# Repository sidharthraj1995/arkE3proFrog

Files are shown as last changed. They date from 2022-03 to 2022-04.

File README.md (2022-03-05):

# arkE3proFrog

- [arkE3proFrog](#arke3profrog)
- [1. Introduction](#1-introduction)
- [2. Hardware](#2-hardware)
  - [2.1. Motion](#21-motion)
    - [X axis](#x-axis)
    - [Y axis](#y-axis)
    - [Z axis](#z-axis)
    - [E](#e)
  - [2.2. Hotend](#22-hotend)
  - [2.3. Electronics](#23-electronics)
- [3. Firmware](#3-firmware)
- [4. Slicer Configuration](#4-slicer-configuration)

# 1. Introduction

Started with stock Creality Ender 3 Pro - Microcenter $99 deal, to learn about the 3D printing.

Replaced the motherboard to employ TMC2208 stepper drivers, linear rails for better motion, dual Z lead
screw for stable printing, Haldis 3D Frog extruder w/ Volcano hotend for HSHF printing, MOSFET for heatbed 
and hotend power, inductive probe for ABL and PEI spring sheet for great first-layer adhesion and large 
touch screen for easy interface.

Running Octoprint on AtomicPi using Docker.

# 2. Hardware

## 2.1. Motion

### X axis

    - Stock Creality 42-34 Stepper Motor.
    - TMC2208
    - MGN12C Linear Rail

### Y axis

    - Stock Creality 42-34 Stepper Motor.
    - TMC2208
    - MGN12C Linear Rail

### Z axis

    - Dual Z setup with 42-34 Stepper Motors.
    - TMC2208
    - V-Slot

### E

    - LDO-36STH20-1004AHG
    - TMC2208
    - Direct Drive setup

## 2.2. Hotend

    - Haldis 3D Frog Extruder w/ Volcano Hotend
    - 24V 50W heat cartridge
    - E3D Semitec 104NT

## 2.3. Electronics

    - BTT SKR 1.4T
    - BTT TFT70 V3.0
    - MOSFET for Hotbed and Hotend
    - ABL: Generic Inductive probe LJ18A3-8-Z/AX

# 3. Firmware

Coming soon.

# 4. Slicer Configuration

Coming soon.

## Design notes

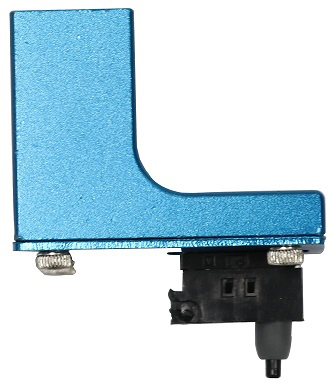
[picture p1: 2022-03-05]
config/Configurations-bugfix-2.0.x/config/examples/delta/Anycubic/Kossel/images/Version1Probe.jpg

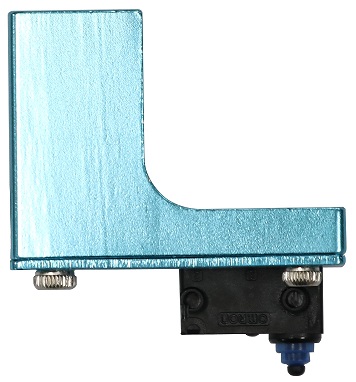
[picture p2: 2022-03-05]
config/Configurations-bugfix-2.0.x/config/examples/delta/Anycubic/Kossel/images/Version2Probe.jpg

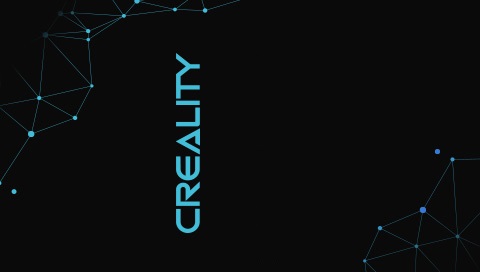
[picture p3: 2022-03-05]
config/Configurations-bugfix-2.0.x/config/examples/Creality/Ender-3 V2/DWIN_SET/0_start.jpg

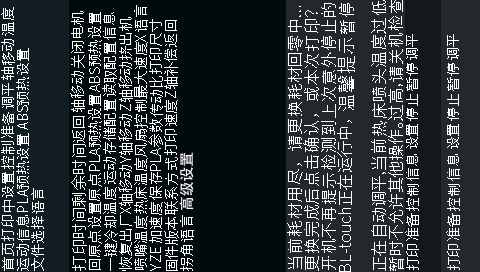
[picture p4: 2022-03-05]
config/Configurations-bugfix-2.0.x/config/examples/Creality/Ender-3 V2/DWIN_SET/2_Chinese.jpg

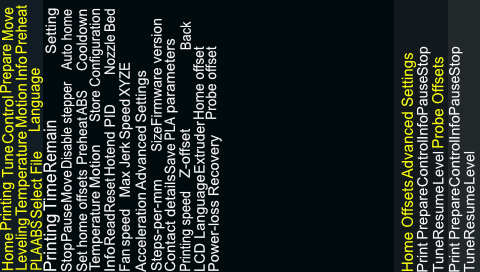
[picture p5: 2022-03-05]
config/Configurations-bugfix-2.0.x/config/examples/Creality/Ender-3 V2/DWIN_SET/1_English.jpg

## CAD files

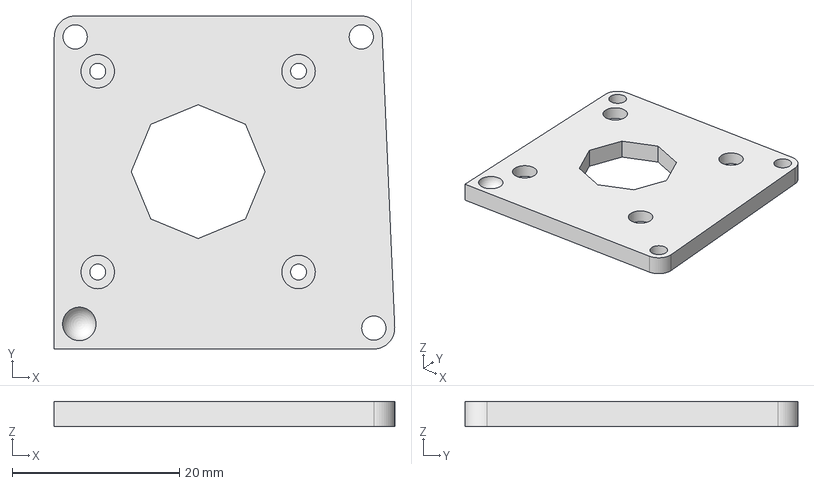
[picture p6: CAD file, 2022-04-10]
3020_4020_fanAdapter/30to40_adapter_v13.FCStd
40.7 x 39.8 x 3.00 mm

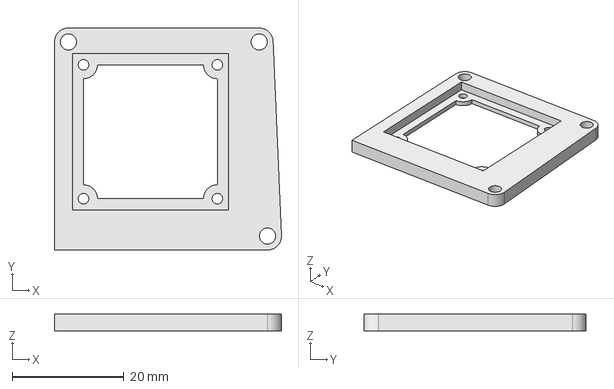
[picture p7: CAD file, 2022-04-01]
3020_4020_fanAdapter/30to40_adapter_v06_midLeft.FCStd
40.7 x 39.8 x 3.00 mm

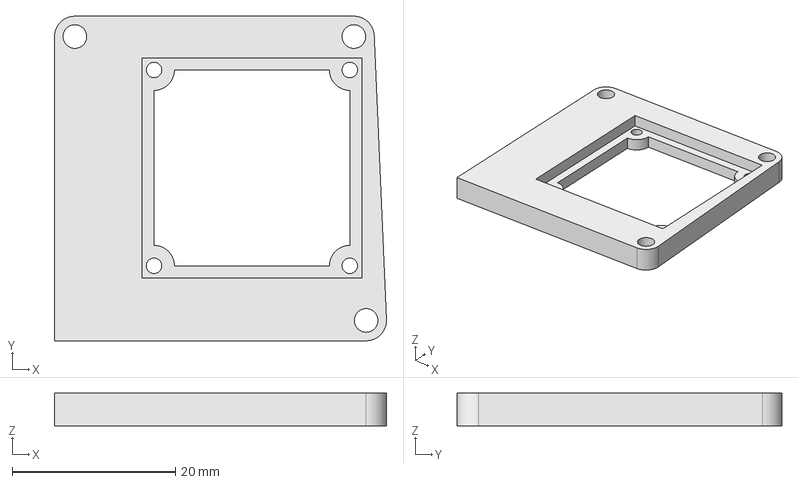
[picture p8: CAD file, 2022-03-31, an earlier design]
3020_4020_fanAdapter/30to40_adapter_v05.FCStd
40.7 x 39.8 x 4.00 mm

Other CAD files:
3020_4020_fanAdapter/30to40_adapter_v05.stl
3020_4020_fanAdapter/30to40_adapter_v13.stl

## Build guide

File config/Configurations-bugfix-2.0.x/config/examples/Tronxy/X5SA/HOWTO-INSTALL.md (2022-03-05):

# Table of Contents <!-- omit in toc -->
- [Save Printer Settings (Optional, but recommended)](#save-printer-settings-optional-but-recommended)
- [Configuring Marlin for your Printer](#configuring-marlin-for-your-printer)
  - [1. Board Version](#1-board-version)
  - [2. Bed size](#2-bed-size)
  - [3. Stepper Drivers](#3-stepper-drivers)
  - [4. Steps / mm](#4-steps--mm)
  - [5. Other Marlin Config](#5-other-marlin-config)
- [Backup your Chitu Firmware (Optional, but strongly recommended)](#backup-your-chitu-firmare-optional-but-strongly-recommended)
- [Flashing Marlin JUST USING SD](#flashing-marlin-just-using-sd)
- [Flashing Marlin Firmware MANUALLY (OBSOLETE!)](#flashing-marlin-firmware-manually-obsolete)
- [Known Issues](#known-issues)

# Save Printer Settings (Optional, but recommended)

You can (OR MUST) dump the current settings of your printer. It may help you to figure out some configs, like steps/mm of your extruder.

1. Create a file named `savesettings.gcode` with the following content:
```
M6046 ; sdcard access
M8512 "currentconfig.gcode" ; save settings to file
```
2. Save it on the printer's SD card
3. Put the card in the printer and "print" this file
4. The printer won't do anything. Just wait a few seconds and stop the print.
5. Your current printer settings are stored in the file: `currentconfig.gcode`

You can read more about it in [this guide](https://www.facebook.com/notes/tronxy-turnigy-x5s-x5sa-x3s-3d-printer-drucker-users/tronxy-firmware-configuration-guide-by-keith-varin-addermk264bit-tuning/649799805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).

Thanks to KEITH VARIN.

# Configuring Marlin for your Printer

You need to edit `Configuration.h` to set up your printer.

## 1. Board Version

For ***V5*** and ***V8***

```cpp
// For V5 and V8
#define MOTHERBOARD BOARD_CHITU3D_V5
```

For ***V6***

```cpp
// For V6
#define MOTHERBOARD BOARD_CHITU3D_V6
```

## 2. Bed size

```cpp
// The size of the printable area
#define X_BED_SIZE 330
#define Y_BED_SIZE 330
...
#define Z_MAX_POS 400
```

## 3. Stepper Drivers

Some Pro models have TMC drivers. The non-Pro models have generic A4988 drivers.

Non-Pro (without TMC Drivers):

```cpp
/**
 * Stepper Drivers
 * ...
 */
#define X_DRIVER_TYPE  A4988
#define Y_DRIVER_TYPE  A4988
#define Z_DRIVER_TYPE  A4988
//#define X2_DRIVER_TYPE A4988
//#define Y2_DRIVER_TYPE A4988
//#define Z2_DRIVER_TYPE A4988
//#define Z3_DRIVER_TYPE A4988
//#define Z4_DRIVER_TYPE A4988
#define E0_DRIVER_TYPE A4988
//#define E1_DRIVER_TYPE A4988
//#define E2_DRIVER_TYPE A4988
//#define E3_DRIVER_TYPE A4988
//#define E4_DRIVER_TYPE A4988
//#define E5_DRIVER_TYPE A4988
//#define E6_DRIVER_TYPE A4988
//#define E7_DRIVER_TYPE A4988
```

Pro (with TMC Drivers):

```cpp
/**
 * Stepper Drivers
 * ...
 */
#define X_DRIVER_TYPE TMC2208_STANDALONE
#define Y_DRIVER_TYPE TMC2208_STANDALONE
#define Z_DRIVER_TYPE TMC2208_STANDALONE
//#define X2_DRIVER_TYPE A4988
//#define Y2_DRIVER_TYPE A4988
//#define Z2_DRIVER_TYPE A4988
//#define Z3_DRIVER_TYPE A4988
//#define Z4_DRIVER_TYPE A4988
#define E0_DRIVER_TYPE TMC2208_STANDALONE
//#define E1_DRIVER_TYPE A4988
//#define E2_DRIVER_TYPE A4988
//#define E3_DRIVER_TYPE A4988
//#define E4_DRIVER_TYPE A4988
//#define E5_DRIVER_TYPE A4988
//#define E6_DRIVER_TYPE A4988
//#define E7_DRIVER_TYPE A4988
```

## 4. Steps / mm

All machines have the same steps for X, Y and Z, and only extruder steps are different (Titan vs. normal).

***! This part can vary from machine to machine !***

One way to know the correct values is to read your `currentconfig.gcode` (saved later):

- `M8009` is the X and Y step/mm.
- `M8010` is the Z step/mm.
- `M8011` is the Extruder step/mm.

Example:

```gcode
M8009 S0.012500;x,y
M8010 S0.002500;z
M8011 S0.010799;e
```

Is equal to:

```gcode
x,y = 1 / 0.012500 = 80
z = 1 / 0.002500 = 400
e = 1 / 0.010799 = 92.60
```

So in Marlin:
```cpp
#define DEFAULT_AXIS_STEPS_PER_UNIT   { 80, 80, 400, 92.6 }
```

Check your values!

Normal non-TMC:
```cpp
/**
 * Default Axis Steps Per Unit (steps/mm)
 * Override with M92
 *                                      X, Y, Z, E0 [, E1[, E2...]]
 */
#define DEFAULT_AXIS_STEPS_PER_UNIT   { 80, 80, 400, 92.6 }
```
Titan Non-PRO:
```cpp
/**
 * Default Axis Steps Per Unit (steps/mm)
 * Override with M92
 *                                      X, Y, Z, E0 [, E1[, E2...]]
 */
#define DEFAULT_AXIS_STEPS_PER_UNIT   { 80, 80, 400, 420 }

// Extruder seems inverted on titan!
#define INVERT_E0_DIR true
```
Titan PRO (tmc):
```cpp
/**
 * Default Axis Steps Per Unit (steps/mm)
 * Override with M92
 *                                      X, Y, Z, E0 [, E1[, E2...]]
 */
#define DEFAULT_AXIS_STEPS_PER_UNIT   { 160, 160, 800, 764 }

// Extruder seems inverted on titan!
#define INVERT_E0_DIR true
```

## 5. Other Marlin Config

You can customize for your own setup. TFT, Baby Steps and a lot of cool stuff are already configured for you.

# Backup your Chitu Firmare (Optional, but strongly recommended)

1. Turn off your printer
2. Open your board case
3. Remove the "boot" jumper (1) as the image.
4. Change the "v source" jumper (2) from 5V to USB.
5. Open [STM Cube Programmer](https://www.st.com/en/development-tools/stm32cubeprog.html) (linux, mac, windows) or [FLASHER-STM32](https://www.st.com/en/development-tools/flasher-stm32.html) (only windows)
6. The size must be **512kb -> 0x80000**
7. Save the file. It must have exactly 524288 bytes (512kb)
8. Disconnect
10. Unplug USB cable
11. Put back the "boot" jumper (1).
12. Put back the "v source" jumper to 5V.

# Flashing Marlin JUST USING SD

Thanks to the amazing work of J.C. Nelson, now we can just use Marlin updating directly from SD!!

1. After you compile Marlin with the above instructions, it will generate a file: `YOUR-MARLIN-DIR/.pio/build/chitu_f103/update.cbd`
2. Turn off your printer
3. Copy the `update.cbd` file to SD card.
4. Put the SD card in your printer.
5. Power it on.
6. It will give some bips. After that, Marlin will start!

SIMPLE AS THAT!

Again, thanks to J.C. Nelson @xC000000

***If you already flashed Marlin the old way then you need restore your Chitu backup to use this method. This will make all your future installs easier.***

# Flashing Marlin Firmware MANUALLY (OBSOLETE!)

OBSOLETE! JUST USE THE FIRST METHOD.

1. Turn off the printer
2. Open the board case
3. Remove the "boot" jumper (1) as the image.
4. Change the V source jumper (2) from 5V to USB.
5. Open [STM Cube Programmer](https://www.st.com/en/development-tools/stm32cubeprog.html) (linux, mac, windows) or [FLASHER-STM32](https://www.st.com/en/development-tools/flasher-stm32.html) (only windows)
6. Flash the YOUR-MARLIN-DIR/.pio/build/chitu_f103/firmware.bin at 0x08000000
7. After the Flash is done, put the back the boot jumper (1) and the V source jumper to 5V.
8. Turn on the printer

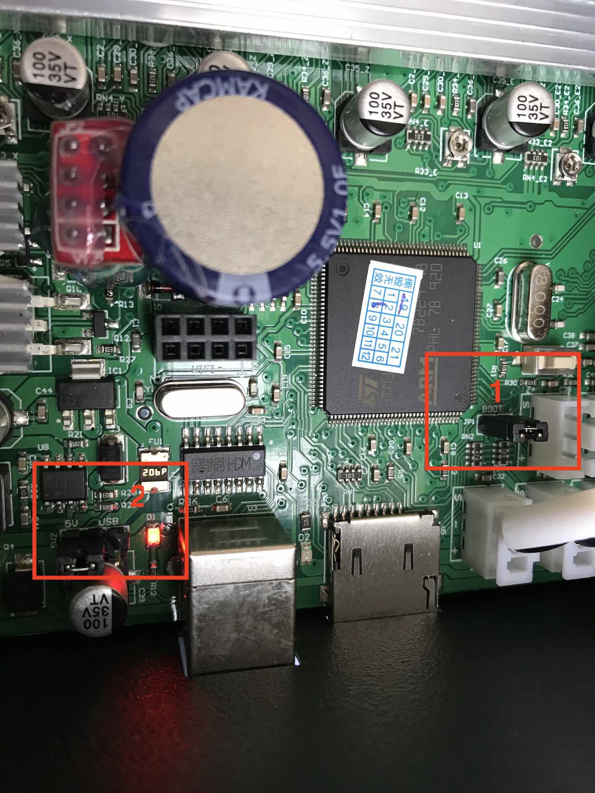
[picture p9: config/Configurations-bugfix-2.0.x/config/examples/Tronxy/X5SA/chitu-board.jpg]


# Known Issues

Some random V5 boards have a problem with the PIN that the Z-MIN Probe is connected to, causing the probe to appear triggered all the time. Due to this issue the probe always fails.

If you have this issue, edit the file: `Marlin/buildroot/share/PlatformIO/variants/CHITU_F103/wirish/boards_setup.cpp`

Change these lines:
```cpp
__weak void board_setup_gpio(void) {
    gpio_init_all();
}
```
To:
```cpp
__weak void board_setup_gpio(void) {
    GPIOA->regs->BSRR = (1U << PA14);
    gpio_init_all();
}
```

A patch may already have been applied to Marlin by the time you read this.

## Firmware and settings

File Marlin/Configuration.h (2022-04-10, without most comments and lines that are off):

#pragma once
#define CONFIG_EXAMPLES_DIR "Creality/Ender-3 Pro/BigTreeTech SKR 1.4 Turbo"
#define CONFIGURATION_H_VERSION 02000903
#define STRING_CONFIG_H_AUTHOR "(ArkhamLab, E3pro_skr1.4T_DDE)" // Who made the changes.
#define SERIAL_PORT -1
#define BAUDRATE 115200
#define SERIAL_PORT_2 0
  #define MOTHERBOARD BOARD_BTT_SKR_V1_4_TURBO
#define CUSTOM_MACHINE_NAME "Frog"
#if LINEAR_AXES >= 4
  #define AXIS4_NAME 'A' // :['A', 'B', 'C', 'U', 'V', 'W']
#endif
#if LINEAR_AXES >= 5
  #define AXIS5_NAME 'B' // :['A', 'B', 'C', 'U', 'V', 'W']
#endif
#if LINEAR_AXES >= 6
  #define AXIS6_NAME 'C' // :['A', 'B', 'C', 'U', 'V', 'W']
#endif
#define EXTRUDERS 1
#define DEFAULT_NOMINAL_FILAMENT_DIA 1.75
#define TEMP_SENSOR_0 5
#define TEMP_SENSOR_1 0
#define TEMP_SENSOR_2 0
#define TEMP_SENSOR_3 0
#define TEMP_SENSOR_4 0
#define TEMP_SENSOR_5 0
#define TEMP_SENSOR_6 0
#define TEMP_SENSOR_7 0
#define TEMP_SENSOR_BED 1
#define TEMP_SENSOR_PROBE 0
#define TEMP_SENSOR_CHAMBER 0
#define TEMP_SENSOR_COOLER 0
#define TEMP_SENSOR_BOARD 0
#define TEMP_SENSOR_REDUNDANT 0
#define DUMMY_THERMISTOR_998_VALUE  25
#define DUMMY_THERMISTOR_999_VALUE 100
#define TEMP_RESIDENCY_TIME         10  // (seconds) Time to wait for hotend to "settle" in M109
#define TEMP_WINDOW                  1  // (°C) Temperature proximity for the "temperature reached" timer
#define TEMP_HYSTERESIS              3  // (°C) Temperature proximity considered "close enough" to the target
#define TEMP_BED_RESIDENCY_TIME     10  // (seconds) Time to wait for bed to "settle" in M190
#define TEMP_BED_WINDOW              1  // (°C) Temperature proximity for the "temperature reached" timer
#define TEMP_BED_HYSTERESIS          3  // (°C) Temperature proximity considered "close enough" to the target
#define TEMP_CHAMBER_RESIDENCY_TIME 10  // (seconds) Time to wait for chamber to "settle" in M191
#define TEMP_CHAMBER_WINDOW          1  // (°C) Temperature proximity for the "temperature reached" timer
#define TEMP_CHAMBER_HYSTERESIS      3  // (°C) Temperature proximity considered "close enough" to the target
#if TEMP_SENSOR_REDUNDANT
  #define TEMP_SENSOR_REDUNDANT_SOURCE    E1  // The sensor that will provide the redundant reading.
  #define TEMP_SENSOR_REDUNDANT_TARGET    E0  // The sensor that we are providing a redundant reading for.
  #define TEMP_SENSOR_REDUNDANT_MAX_DIFF  10  // (°C) Temperature difference that will trigger a print abort.
#endif
#define HEATER_0_MINTEMP   0
#define HEATER_1_MINTEMP   5
#define HEATER_2_MINTEMP   5
#define HEATER_3_MINTEMP   5
#define HEATER_4_MINTEMP   5
#define HEATER_5_MINTEMP   5
#define HEATER_6_MINTEMP   5
#define HEATER_7_MINTEMP   5
#define BED_MINTEMP        0
#define CHAMBER_MINTEMP    5
#define HEATER_0_MAXTEMP 285
#define HEATER_1_MAXTEMP 275
#define HEATER_2_MAXTEMP 275
#define HEATER_3_MAXTEMP 275
#define HEATER_4_MAXTEMP 275
#define HEATER_5_MAXTEMP 275
#define HEATER_6_MAXTEMP 275
#define HEATER_7_MAXTEMP 275
#define BED_MAXTEMP      120
#define CHAMBER_MAXTEMP  60
#define HOTEND_OVERSHOOT 15   // (°C) Forbid temperatures over MAXTEMP - OVERSHOOT
#define BED_OVERSHOOT    10   // (°C) Forbid temperatures over MAXTEMP - OVERSHOOT
#define COOLER_OVERSHOOT  2   // (°C) Forbid temperatures closer than OVERSHOOT
#define PIDTEMP
#define BANG_MAX 255     // Limits current to nozzle while in bang-bang mode; 255=full current
#define PID_MAX BANG_MAX // Limits current to nozzle while PID is active (see PID_FUNCTIONAL_RANGE below); 255=full current
#define PID_K1 0.95      // Smoothing factor within any PID loop
  #define PID_EDIT_MENU         // Add PID editing to the "Advanced Settings" menu. (~700 bytes of PROGMEM)
  #define PID_AUTOTUNE_MENU     // Add PID auto-tuning to the "Advanced Settings" menu. (~250 bytes of PROGMEM)
    #define DEFAULT_Kp  15.33 //myFrog HOTEND values - 220C
    #define DEFAULT_Ki   0.98 // Calculate your values
    #define DEFAULT_Kd  59.89 // M303 E0 S220 C10
#define PIDTEMPBED
#define MAX_BED_POWER 255 // limits duty cycle to bed; 255=full current
  #define DEFAULT_bedKp 111.35
  #define DEFAULT_bedKi  21.41
  #define DEFAULT_bedKd 386.02
#define MAX_CHAMBER_POWER 255 // limits duty cycle to chamber heater; 255=full current
  #define PID_FUNCTIONAL_RANGE 10 // If the temperature difference between the target temperature and the actual temperature
#define PREVENT_COLD_EXTRUSION
#define EXTRUDE_MINTEMP 180
#define PREVENT_LENGTHY_EXTRUDE
#define EXTRUDE_MAXLENGTH 250
#define THERMAL_PROTECTION_HOTENDS // Enable thermal protection for all extruders
#define THERMAL_PROTECTION_BED     // Enable thermal protection for the heated bed
#define USE_XMIN_PLUG
#define USE_YMIN_PLUG
#define USE_ZMIN_PLUG
#define ENDSTOPPULLUPS
#define X_MIN_ENDSTOP_INVERTING false // Set to true to invert the logic of the endstop.
#define Y_MIN_ENDSTOP_INVERTING false // Set to true to invert the logic of the endstop.
#define Z_MIN_ENDSTOP_INVERTING true // Set to true to invert the logic of the endstop.
#define I_MIN_ENDSTOP_INVERTING false // Set to true to invert the logic of the endstop.
#define J_MIN_ENDSTOP_INVERTING false // Set to true to invert the logic of the endstop.
#define K_MIN_ENDSTOP_INVERTING false // Set to true to invert the logic of the endstop.
#define X_MAX_ENDSTOP_INVERTING false // Set to true to invert the logic of the endstop.
#define Y_MAX_ENDSTOP_INVERTING false // Set to true to invert the logic of the endstop.
#define Z_MAX_ENDSTOP_INVERTING false // Set to true to invert the logic of the endstop.
#define I_MAX_ENDSTOP_INVERTING false // Set to true to invert the logic of the endstop.
#define J_MAX_ENDSTOP_INVERTING false // Set to true to invert the logic of the endstop.
#define K_MAX_ENDSTOP_INVERTING false // Set to true to invert the logic of the endstop.
#define Z_MIN_PROBE_ENDSTOP_INVERTING true // Set to true to invert the logic of the probe.
#define X_DRIVER_TYPE  TMC2208
#define Y_DRIVER_TYPE  TMC2208
#define Z_DRIVER_TYPE  TMC2208
#define Z2_DRIVER_TYPE TMC2208  // Frog: To fire up E1 port to be used as Z2
#define E0_DRIVER_TYPE TMC2208
#define DEFAULT_AXIS_STEPS_PER_UNIT   { 80, 80, 400, 421.32 }   // LDO-36STH20-1004AHG Extruder Steps
#define DEFAULT_MAX_FEEDRATE          { 500, 500, 15, 25 }
#define DEFAULT_MAX_ACCELERATION      { 2500, 2500, 200, 5000 }
#define DEFAULT_ACCELERATION          1500    // X, Y, Z and E acceleration for printing moves
#define DEFAULT_RETRACT_ACCELERATION  1250    // E acceleration for retracts
#define DEFAULT_TRAVEL_ACCELERATION   2500    // X, Y, Z acceleration for travel (non printing) moves
#define DEFAULT_EJERK    9.0  // May be used by Linear Advance
  #define JUNCTION_DEVIATION_MM 0.022 // (mm) Distance from real junction edge
  #define JD_HANDLE_SMALL_SEGMENTS    // Use curvature estimation instead of just the junction angle
#define S_CURVE_ACCELERATION
#define Z_MIN_PROBE_USES_Z_MIN_ENDSTOP_PIN
#define USE_PROBE_FOR_Z_HOMING
#define FIX_MOUNTED_PROBE
#define NOZZLE_TO_PROBE_OFFSET { -42, -1, 0 }
#define PROBING_MARGIN 30
#define XY_PROBE_FEEDRATE (200*60)
#define Z_PROBE_FEEDRATE_FAST (8*60)
#define Z_PROBE_FEEDRATE_SLOW (Z_PROBE_FEEDRATE_FAST / 2)
#define MULTIPLE_PROBING 2
#define Z_CLEARANCE_DEPLOY_PROBE    5 // Z Clearance for Deploy/Stow
#define Z_CLEARANCE_BETWEEN_PROBES  3 // Z Clearance between probe points
#define Z_CLEARANCE_MULTI_PROBE     3 // Z Clearance between multiple probes
#define Z_AFTER_PROBING             5 // Z position after probing is done
#define Z_PROBE_LOW_POINT          -3 // Farthest distance below the trigger-point to go before stopping
#define Z_PROBE_OFFSET_RANGE_MIN -20
#define Z_PROBE_OFFSET_RANGE_MAX 20
#define Z_MIN_PROBE_REPEATABILITY_TEST
#define PROBING_HEATERS_OFF       // Turn heaters off when probing
#define PROBING_ESTEPPERS_OFF     // Turn all extruder steppers off when probing
#define X_ENABLE_ON 0
#define Y_ENABLE_ON 0
#define Z_ENABLE_ON 0
#define E_ENABLE_ON 0 // For all extruders
#define DISABLE_X false
#define DISABLE_Y false
#define DISABLE_Z false
#define DISABLE_E false             // Disable the extruder when not stepping
#define DISABLE_INACTIVE_EXTRUDER   // Keep only the active extruder enabled
#define INVERT_X_DIR true
#define INVERT_Y_DIR true
#define INVERT_Z_DIR false
#define INVERT_E0_DIR true
#define INVERT_E1_DIR false
#define INVERT_E2_DIR false
#define INVERT_E3_DIR false
#define INVERT_E4_DIR false
#define INVERT_E5_DIR false
#define INVERT_E6_DIR false
#define INVERT_E7_DIR false Z_HOMING_HEIGHT  4      // (mm) Minimal Z height before homing (G28) for Z clearance above the bed, clamps, ...
#define Z_AFTER_HOMING  10      // (mm) Height to move to after homing Z
#define Z_AFTER_HOMING  10      // (mm) Height to move to after homing Z
#define X_HOME_DIR -1
#define Y_HOME_DIR -1
#define Z_HOME_DIR -1
#define X_BED_SIZE 235
#define Y_BED_SIZE 235
#define X_MIN_POS -1
#define Y_MIN_POS -36
#define Z_MIN_POS 0
#define X_MAX_POS X_BED_SIZE
#define Y_MAX_POS Y_BED_SIZE
#define Z_MAX_POS 250
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

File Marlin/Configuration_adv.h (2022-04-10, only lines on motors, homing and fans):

#define E0_AUTO_FAN_PIN P2_04
#define E1_AUTO_FAN_PIN -1
#define E2_AUTO_FAN_PIN -1
#define E3_AUTO_FAN_PIN -1
#define E4_AUTO_FAN_PIN -1
#define E5_AUTO_FAN_PIN -1
#define E6_AUTO_FAN_PIN -1
#define E7_AUTO_FAN_PIN -1
#define CHAMBER_AUTO_FAN_PIN -1
#define COOLER_AUTO_FAN_PIN -1
#define COOLER_FAN_PIN -1
#define HOMING_BUMP_MM      { 5, 5, 2 }       // (mm) Backoff from endstops after first bump
#define HOMING_BUMP_DIVISOR { 2, 2, 4 }       // Re-Bump Speed Divisor (Divides the Homing Feedrate)
#define HOMING_BACKOFF_POST_MM { 2, 2, 2 }  // (mm) Backoff from endstops after homing
#define QUICK_HOME                            // If G28 contains XY do a diagonal move first
  #define HOME_AFTER_G34
#define MICROSTEP_MODES { 16, 16, 16, 16, 16, 16 } // [1,2,4,8,16]
  #define BABYSTEP_WITHOUT_HOMING
#define LIN_ADVANCE
  #define EXTRA_LIN_ADVANCE_K // Enable for second linear advance constants
  #define LIN_ADVANCE_K 0.0    // SET IN GCODE ------   Unit: mm compression per 1mm/s extruder speed
#define ADVANCED_PAUSE_FEATURE
  #define ADVANCED_PAUSE_PURGE_FEEDRATE        5  // (mm/s) Extrude feedrate (after loading). Should be slower than load feedrate.
  #define ADVANCED_PAUSE_PURGE_LENGTH         50  // (mm) Length to extrude after loading.
  #define ADVANCED_PAUSE_RESUME_PRIME          0  // (mm) Extra distance to prime nozzle after returning from park.
    #define X_CURRENT       580        // (mA) RMS current. Multiply by 1.414 for peak current.
    #define X_CURRENT_HOME  (X_CURRENT/2)  // (mA) RMS current for sensorless homing
    #define X_MICROSTEPS     16        // 0..256
    #define Y_CURRENT       580
    #define Y_CURRENT_HOME  (Y_CURRENT/2)
    #define Y_MICROSTEPS     16
    #define Z_CURRENT       580
    #define Z_CURRENT_HOME  Z_CURRENT
    #define Z_MICROSTEPS     16
    #define Z2_CURRENT      580
    #define Z2_CURRENT_HOME Z2_CURRENT
    #define Z2_MICROSTEPS    Z_MICROSTEPS
    #define E0_CURRENT      680
    #define E0_MICROSTEPS    16
    #define CURRENT_STEP_DOWN     50  // [mA]
    #define REPORT_CURRENT_CHANGE
  #define X_HYBRID_THRESHOLD     100  // [mm/s]
  #define X2_HYBRID_THRESHOLD    100
  #define Y_HYBRID_THRESHOLD     100
  #define Y2_HYBRID_THRESHOLD    100
  #define Z_HYBRID_THRESHOLD       3
  #define Z2_HYBRID_THRESHOLD      3
  #define Z3_HYBRID_THRESHOLD      3
  #define Z4_HYBRID_THRESHOLD      3
  #define I_HYBRID_THRESHOLD       3
  #define J_HYBRID_THRESHOLD       3
  #define K_HYBRID_THRESHOLD       3
  #define E0_HYBRID_THRESHOLD     30
  #define E1_HYBRID_THRESHOLD     30
  #define E2_HYBRID_THRESHOLD     30
  #define E3_HYBRID_THRESHOLD     30
  #define E4_HYBRID_THRESHOLD     30
  #define E5_HYBRID_THRESHOLD     30
  #define E6_HYBRID_THRESHOLD     30
  #define E7_HYBRID_THRESHOLD     30

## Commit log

2022-03-05 Removed junk
    [Configuration.h, Configuration1.h, ConfigurationOld.h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]
2022-03-06 - Adjusted load/unload length - Reset feature values - Set PID values - Set Home values
    [Configuration.h, Configuration_adv.h]
2022-03-28 enabled FW retract
    [Configuration_adv.h]
2022-03-31 Added 30 to 40 fan adapter plate
    [30to40_adapter_v01.stl, 30to40_adapter_v05.FCStd, 30to40_adapter_v05.stl]
2022-04-01 Updated 3010 to 4020 Blower adapter
    [30to40_adapter_v06_midLeft.FCStd, 30to40_adapter_v06_midLeft.stl]
2022-04-04 Final Frog cleanup - added FAN scaling - Updated default accel
    [Configuration.h, Configuration_adv.h]
2022-04-10 - Final FAN plate - Tested `Backlash Compensation`, did not work :P - Fine tune values - Estep
    [30to40_adapter_v01.stl, 30to40_adapter_v06_midLeft.stl, 30to40_adapter_v13.FCStd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]

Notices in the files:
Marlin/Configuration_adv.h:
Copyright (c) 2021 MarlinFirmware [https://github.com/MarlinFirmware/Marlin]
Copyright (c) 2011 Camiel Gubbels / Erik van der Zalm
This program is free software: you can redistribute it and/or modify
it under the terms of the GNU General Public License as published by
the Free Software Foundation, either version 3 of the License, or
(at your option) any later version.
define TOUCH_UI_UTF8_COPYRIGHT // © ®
